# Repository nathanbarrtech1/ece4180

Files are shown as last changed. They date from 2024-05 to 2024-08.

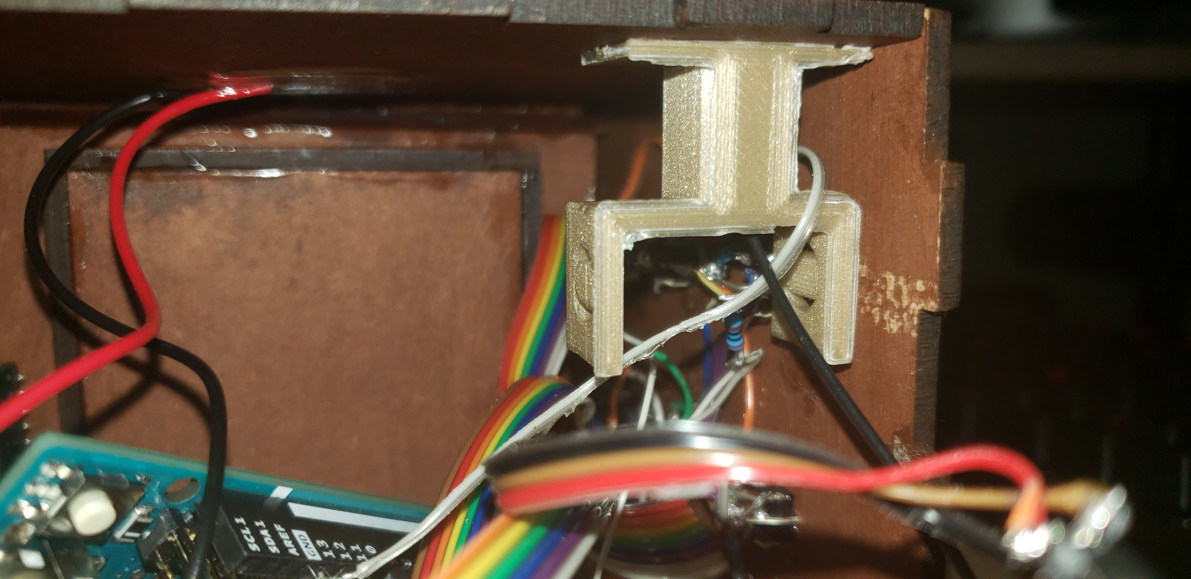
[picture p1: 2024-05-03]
3D Print/image.jpg

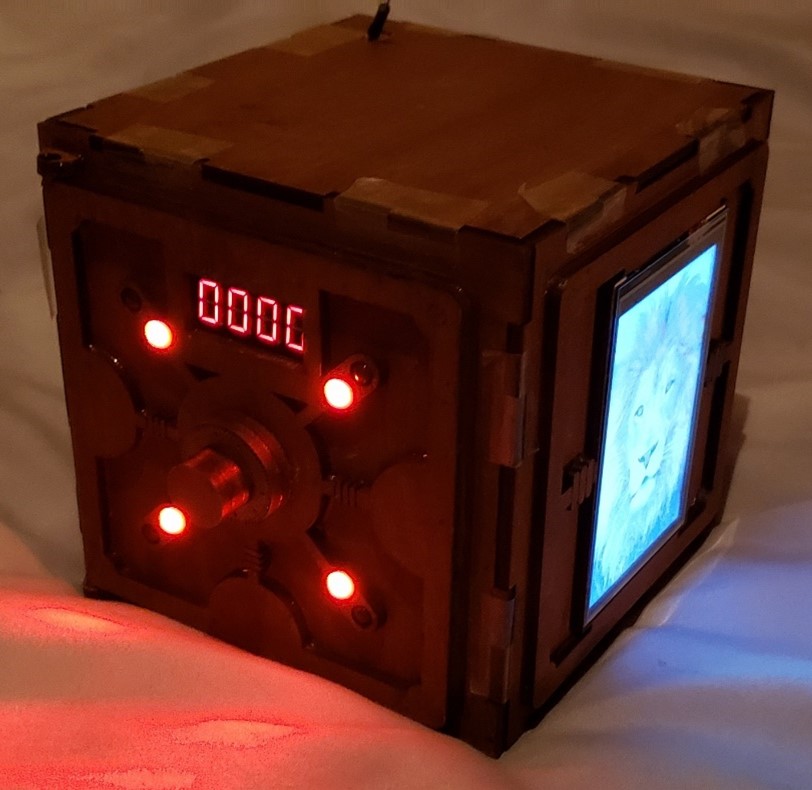
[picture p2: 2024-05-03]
pictures/frontviewon.jpg

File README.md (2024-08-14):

# Puzzle Box

This project goal was to develop a puzzle box consisting of multiple puzzles:

1. LCD Sliding Block Puzzle
2. Accelerometer Puzzle
3. Lights Up Game Puzzle
4. Knocking Puzzle
5. Code Guessing Puzzle

### Notes during recreation

Must include the SPFD5408 libary to arduino along with others in the library manager to compile all code.

Also, adjust the outer dimensions of the box in the laser cut by approximately 10% to adjust for inadequate space during my project.

Some of the laser cut designs are not correct, many last minute changes were made and lost after cutting.

### Below is the demo video for the puzzle box
Puzzle Box (https://www.youtube.com/watch?v=jFf0oDgVzTA)

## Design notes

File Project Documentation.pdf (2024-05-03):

## Arduino Based Puzzle Box

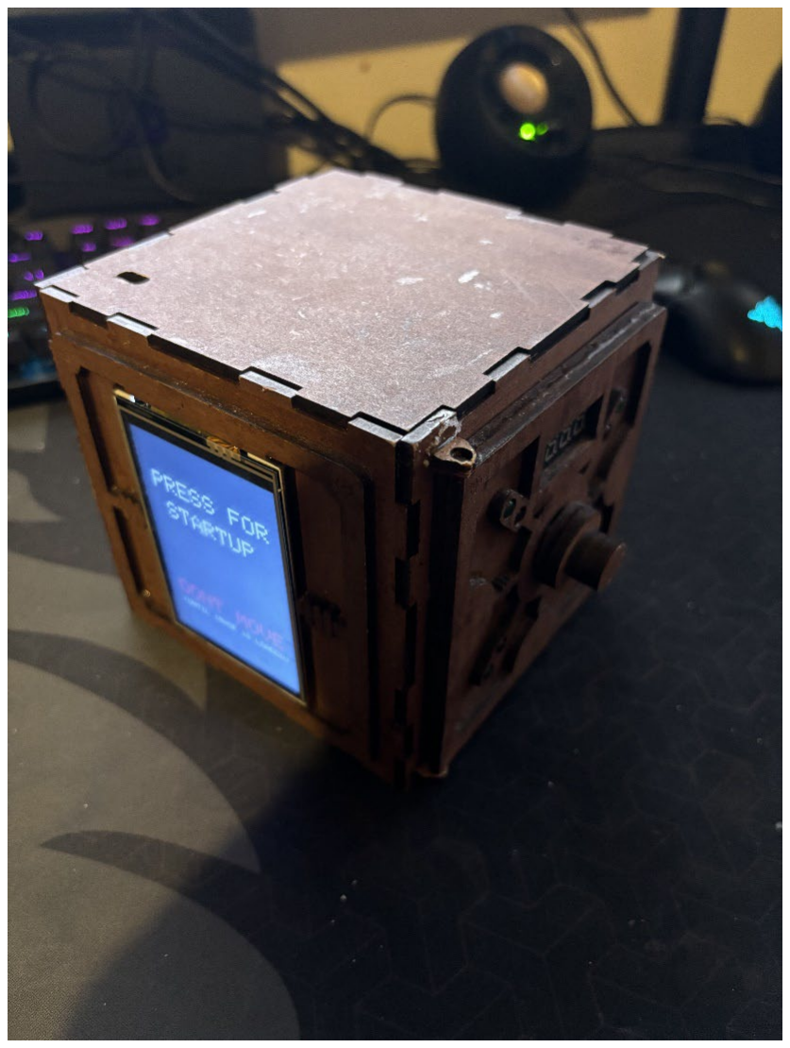
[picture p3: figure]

Description of Prototype
The project is a buzzle box that has three interlocking interconnected puzzles that must be solved to open the puzzle box and retrieve the prize inside.
The first puzzle is a knocking program that requires the user to input a specific sequence of knocks to solve the puzzle. An LED will light up for every correct knock. If a knock is incorrect, 4 green LEDs will flash for too fast and 4 red LEDs will flash for too slow. There is a total of 8 knocks in the sequence.

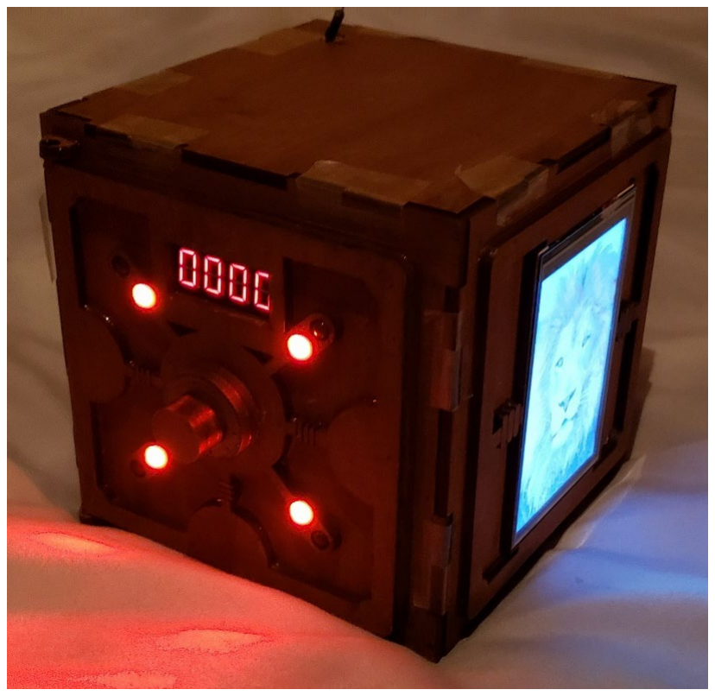
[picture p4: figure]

The second puzzle is a touchscreen LCD that contains a 3x3 sliding block puzzle. The image shows the solved puzzle on the right side of the box. When not solved, there will be 8 image tiles with an empty space for the ninth. The image tiles can be moved to the empty space thus emptying their previous spots. The goal is to organize the image so that all tiles are in the right spot. Once that is done, the image will complete itself and only one puzzle will be left. The third puzzle is a four-digit guessing game where red LEDs will light up for every correct number in the wrong position. For example, if the code is 0123, inputting 1000 will light

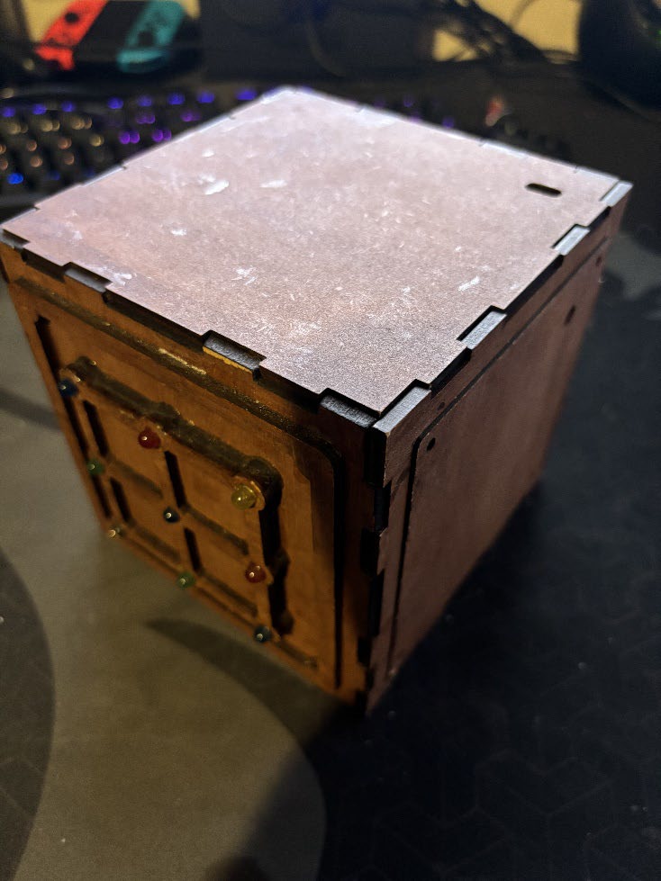
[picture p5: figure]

up 2 red LEDs and 1032 will light up 4 red LEDs. Green LEDs will light up for every correct number in the correct position. For example, if the code is 0123, inputting 0100 will light up 2 green LEDs and 0124 will light up 3 green LEDs.
There is a fourth puzzle that features a 3x3 grid of LEDs and buttons on the LED screen where pushing one of the LED button combos will turn on all adjacent lights that are off and turn off all adjacent light that are on (including itself).
There is a fifth puzzle where the puzzle box is rotated a certain amount then a pushbutton is pressed. The lights on the front will light up green when the player has not moved far enough, red when the player moved too far, and red and green when the player succeeded. This continues for four iterations where the player has five attempts per iteration before the puzzle restarts. Video Demo (https://www.youtube.com/watch?v=jFf0oDgVzTA)

Difficulties faced
There were a lot of problems that cropped up as the project continued. The biggest issue is that, by using the same size of the box as the original design while simultaneously adding a multitude of parts, my puzzle box ran out of room quite quickly. Another problem was the soldering. I soldered over 70 connections which was extremely difficult considering the fact that these connections would be placed side by side. The soldering was redone with crimping for a much cleaner and less error-prone circuit.
Furthermore, for reasons still unknown, I was unable to properly solder the middle LED of the 3x3 grid. The connection would always depend on how I positions the soldered parts and I would have to hold it in place with my finger for the connection to work, something impossible to maintain since I cant always hold that connection. It was also extremely difficult and time-consuming to glue in the push buttons such that they would not lock down the LEDs preventing them from pushing the button. I had to remove button, scrape off the glue, and reglue multiple times. I also had to flatten the LED wires at the LED’s base then glue the whole base creating a flat surface to interact with the push button. Because of this, the pushbuttons were removed and the LEDS were instead adjusted using the touchscreen.
Another weird issue was that the rotary encoder seemed to create some sort of open circuit on the Arduino that could only be solved by connecting a wire to pin 2 (a pin that is not being used). Only pin 2 worked and other unused pins did not. Furthermore, the pin had to be closed manually by pinching the other end of the wire with two fingers to close the circuit. Connecting the wire to 5V or GND did not solve the issue and using fingers was the only solution I found. This issue was solved by properly resoldering all components, crimping, and heat shrinking.

Some other difficulties include needing to laser cut the same part multiple times because of issues with the dimensions and wasting time due to shipping time. In the end, a box was completed, but it is too small to properly fit the components which has caused some issues from poor wiring to unstable connections.

Parts list:
- TFT touchscreen LCD
- Arduino MEGA
- Many wires, solder, crimp
- Rotary Encoder
- 17 LEDs and 220 Ω resistors
- 9 Buttons and 1MΩ resistors
- Seven segment display
- 1/8. in MDF
- 2 9V batteries
- Glue
- Servo motor
- Accelerometer
- SD reader

Algorithms used
The only algorithms used were those that checked if a knock was correct, whether to 4-digit code was correct, whether a chosen tile can be moved to a chosen location, and other minor algorithms that helped the aforementioned algorithms become simpler. I did not use any of the well-known algorithms like bubble sort and all of my algorithms were self-made.

Pin List

Object | Name | Pin
Servo Motor | Servo Pin | 23
Rotary Encoder | ButtonPin | 17
Rotary Encoder | PinA | 19
Rotary Encoder | PinB | 18
LCD | LCD Pin | 9
TFT | LCD_RD | A0
TFT | LCD_WR | A1
TFT | LCD_CD | A2
TFT | LCD_CS | A3
TFT | LCD_RESET | A4
Touchscreen | YP | A2
Touchscreen | XM | A3
Touchscreen | YM | 8
Touchscreen | XP | 9
Touchscreen | SD_CS | 53
Piezo | Sensor | A8
LED | correctNumLEDs | 27
LED | correctNumLEDs | 29
LED | correctNumLEDs | 37
LED | correctNumLEDs | 35
LED | correctPlaceLEDs | 25

LED | correctPlaceLEDs | 31
LED | correctPlaceLEDs | 39
LED | correctPlaceLEDs | 33
LED | {1,1} | 14
LED | {1,2} | 41
LED | {1,3} | 10
LED | {2,1} | 15
LED | {2,2} | 43
LED | {2,3} | 11
LED | {3,1} | 16
LED | {3,2} | 45
LED | {3,3} | 12
SevSeg | digitPins | 22
SevSeg | digitPins | 34
SevSeg | digitPins | 38
SevSeg | digitPins | 44
SevSeg | segmentPins | 26
SevSeg | segmentPins | 42
SevSeg | segmentPins | 36
SevSeg | segmentPins | 28
SevSeg | segmentPins | 24
SevSeg | segmentPins | 30
SevSeg | segmentPins | 40

SevSeg | segmentPins | 32

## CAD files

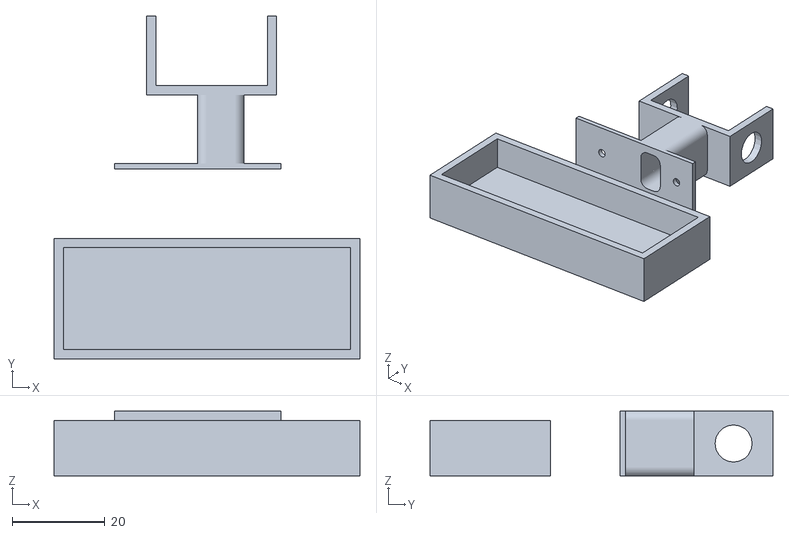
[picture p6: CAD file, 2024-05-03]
3D Print/parts.stl
66.0 x 74.0 x 14.0

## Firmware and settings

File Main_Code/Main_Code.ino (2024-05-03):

/////////////////////////////////
/////////// INCLUDES ////////////
/////////////////////////////////

#include <Servo.h>
#include <Encoder.h>
#include "SevSeg.h"
#include <TimerOne.h>
#include <SPFD5408_Adafruit_GFX.h>
#include <SPFD5408_Adafruit_TFTLCD.h>
#include <SPI.h>
#include <SD.h>
#include <SPFD5408_TouchScreen.h>

/////////////////////////////////
/////// SHARED CONSTANTS ////////
/////////////////////////////////

#define NUM_PUZZLES     5

#define VAULT           0
#define LCD             1
#define KNOCK           2
#define LEDS            3
#define ACC             4

#define DEBUG           1
#define SERVOPIN        23

/////////////////////////////////
//////// VAULT CONSTANTS ////////
/////////////////////////////////

#define ButtonPin       17
#define PinA            19
#define PinB            18
#define DEBOUNCE_DELAY  150

/////////////////////////////////
//////// KNOCK CONSTANTS ////////
/////////////////////////////////

#define NUM_OF_KNOCKS 8

/////////////////////////////////
//////// KNOCK CONSTANTS ////////
/////////////////////////////////

#define LCD_PIN 9

/////////////////////////////////
///////// LED CONSTANTS /////////
/////////////////////////////////

#define BLACK   0x0000
#define BLUE    0x001F
#define RED     0xF800
#define GREEN   0x07E0
#define CYAN    0x07FF
#define MAGENTA 0xF81F
#define YELLOW  0xFFE0
#define WHITE   0xFFFF

#define LCD_RD A0
#define LCD_WR A1
#define LCD_CD A2
#define LCD_CS A3
#define LCD_RESET A4

#define YP A2
#define XM A3
#define YM 8
#define XP 9
#define SD_CS 53

#define COMPLETE A5
#define WIDTH 106
#define HEIGHT 160

#define LED_DEBOUNCE 350

/////////////////////////////////
/////// SHARED VARIABLES ////////
/////////////////////////////////

int valid_puzzles[NUM_PUZZLES] = {false, false, true, false, false};
int solved_puzzles[NUM_PUZZLES] = {false, false, false, false, false};
Adafruit_TFTLCD tft(LCD_CS, LCD_CD, LCD_WR, LCD_RD, A4);
TouchScreen ts = TouchScreen(XP, YP, XM, YM, 300);

/////////////////////////////////
//////// VAULT VARIABLES ////////
/////////////////////////////////

Encoder myEnc(PinA,  PinB);
SevSeg sevseg;
Servo lockServo;

int currButtonVal;
int lastButtonVal;
int rightPos;
int rightNum;


int corrCode[4];
int guessCode[4] = {0, 0, 0, 0};
byte correctNumLEDs[4] =  {27, 29, 37, 35};  //Pin numbers for correct number LEDs (Indicate a correct digit)
byte correctPlaceLEDs[4] = {25, 31, 39, 33}; //Pin numbers for correct place LEDs (Indicate a correct digit in the correct place)

unsigned long buttonTime = 0;
int currNum = 0;
int numGuesses = 0;
int numPresses = 0;
int tempPos = -999;
long oldPosition  = -999;
long newPosition = -999;

/////////////////////////////////
//////// KNOCK VARIABLES ////////
/////////////////////////////////

const int sensorPin = A8;
const int threshold = 300;
byte LED[NUM_OF_KNOCKS] = {25, 31, 39, 33, 27, 29, 37, 35};
int minKnockTimes[NUM_OF_KNOCKS] = {0,      0   , 1000, 2000, 0   , 1000, 3000, 0   };
int maxKnockTimes[NUM_OF_KNOCKS] = {100000, 1000, 3000, 4000, 1000, 3000, 6000, 4000};
const int ledPin[3][3]    = {{5,  6,  7} , {8,  9,  10}, {11, 12, 13}};
int currentKnock = 0;
long int timer;
bool knockValid = false;

/////////////////////////////////
///////// LED VARIABLES /////////
/////////////////////////////////

int ledColors[3][3] =
{
  {BLUE,  RED,    YELLOW},
  {GREEN, BLUE,   RED},
  {WHITE, GREEN,  BLUE}
};

const int LED_PUZZLE[3][3] =
{
  {14, 41, 10},
  {15, 43, 11},
  {16, 45, 12}
};

bool ledOn[3][3] =
{
  {LOW, LOW, LOW},
  {LOW, LOW, LOW},
  {LOW, LOW, LOW}
};

long ledTimer = 0;

void setup()
{
  /////////////////////////////////
  ////////// SHARED SETUP /////////
  /////////////////////////////////
  
  Serial.begin (9600);
  Serial.println("BEGIN!");

  /////////////////////////////////
  ////////// VAULT SETUP //////////
  /////////////////////////////////
  
  pinMode(ButtonPin, INPUT_PULLUP);

  attachInterrupt(digitalPinToInterrupt(PinA), updateEncoder, CHANGE);
  
  lockServo.attach(SERVOPIN);
  lockServo.write(90);
  randomSeed(analogRead(A7));
  generateNewCode();

  for (int i = 0 ; i <= 3 ; i++)
  {
    pinMode(correctNumLEDs[i], OUTPUT);
    pinMode(correctPlaceLEDs[i], OUTPUT);
  }

  byte numDigits = 4;
  byte digitPins[] = {22, 34, 38, 44};
  byte segmentPins[] = {26, 42, 36, 28, 24, 30, 40, 32};

  bool resistorsOnSegments = true;
  byte hardwareConfig = COMMON_CATHODE;
  sevseg.begin(hardwareConfig, numDigits, digitPins, segmentPins, resistorsOnSegments);
  sevseg.setBrightness(90);

  /////////////////////////////////
  ////////// KNOCK SETUP //////////
  /////////////////////////////////

  pinMode(sensorPin, INPUT);

  pinMode(LCD_PIN, INPUT_PULLUP);

  if (!DEBUG)
    generateKnock();

  /////////////////////////////////
  /////////// TFT SETUP ///////////
  /////////////////////////////////


  /////////////////////////////////
  /////////// LED SETUP ///////////
  /////////////////////////////////

  start();
  LED_PUZZLE_SETUP();

}

void loop()
{
  sevseg.refreshDisplay();
  if (solved_puzzles[LCD] && solved_puzzles[KNOCK] && !solved_puzzles[VAULT])
  {
    valid_puzzles[VAULT] = true;
  }

  if (valid_puzzles[LCD])
  {
    
  }

  ////////////////////////////////
  ///////////// SERVO ////////////
  ////////////////////////////////

  if (checkSolved())
    lockServo.write(130);

  ////////////////////////////////
  ////////// VAULT LOOP //////////
  ////////////////////////////////

  if (valid_puzzles[VAULT])
  {
    if (numPresses == 4) checkNumber();
    else updateNumber();
  }
  else Serial.println("HI");

  ////////////////////////////////
  ////////// KNOCK LOOP //////////
  ////////////////////////////////

  if (valid_puzzles[KNOCK])
  {
    if (currentKnock == 8)
    {
      resetKnocks();
      Celebration();
      valid_puzzles[KNOCK] = false;
      solved_puzzles[KNOCK] = true;
    }
    readAndCheckKnock();
  }

  ////////////////////////////////
  /////////// LED LOOP ///////////
  ////////////////////////////////

  if (valid_puzzles[LEDS] && millis() - ledTimer > LED_DEBOUNCE)
  {
    LED_PUZZLE_ALG();
    IS_LED_PUZZLE_SOLVED();
  }
}
/////////////////////////////////
//////// SHARED FUNCTIONS ///////
/////////////////////////////////

int getCoordinate(TSPoint p, char axis)
{
  if (axis == 'y')
  {
    int x = map(p.y, 112, 800, 0, tft.width()  - 1);

    if       (x >= 2 * tft.width() / 3)   return 0;
    else if  (x >=     tft.width() / 3)   return 1;
    else                                  return 2;
  }

  if (axis == 'x')
  {
    int y = map(p.x,  96, 947, 0, tft.height() - 1);

    if       (y >= 2 * tft.height() / 3)  return 0;
    else if  (y >=     tft.height() / 3)  return 1;
    else                                  return 2;
  }
}

#define BUFFPIXEL 20           //Drawing speed, 20 is meant to be the best but you can use 60 altough it takes a lot of uno's RAM         

//Drawing function, reads the file from the SD card and do the
//conversion and drawing, also it shows messages on the Serial monitor in case of a problem
//No touchy to this function :D

void bmpDraw(char *filename, int x, int y) {

  File     bmpFile;
  int      bmpWidth, bmpHeight;   // W+H in pixels
  uint8_t  bmpDepth;              // Bit depth (currently must be 24)
  uint32_t bmpImageoffset;        // Start of image data in file
  uint32_t rowSize;               // Not always = bmpWidth; may have padding
  uint8_t  sdbuffer[3 * BUFFPIXEL]; // pixel in buffer (R+G+B per pixel)
  uint16_t lcdbuffer[BUFFPIXEL];  // pixel out buffer (16-bit per pixel)
  uint8_t  buffidx = sizeof(sdbuffer); // Current position in sdbuffer
  boolean  goodBmp = false;       // Set to true on valid header parse
  boolean  flip    = true;        // BMP is stored bottom-to-top
  int      w, h, row, col;
  uint8_t  r, g, b;
  uint32_t pos = 0, startTime = millis();
  uint8_t  lcdidx = 0;
  boolean  first = true;

  if ((x >= tft.width()) || (y >= tft.height())) return;

  Serial.println();
  progmemPrint(PSTR("Loading image '"));
  Serial.print(filename);
  Serial.println('\'');
  // Open requested file on SD card
  if ((bmpFile = SD.open(filename)) == NULL) {
    progmemPrintln(PSTR("File not found"));
    return;
  }

  // Parse BMP header
  if (read16(bmpFile) == 0x4D42) { // BMP signature
    progmemPrint(PSTR("File size: ")); Serial.println(read32(bmpFile));
    (void)read32(bmpFile); // Read & ignore creator bytes
    bmpImageoffset = read32(bmpFile); // Start of image data
    progmemPrint(PSTR("Image Offset: ")); Serial.println(bmpImageoffset, DEC);
    // Read DIB header
    progmemPrint(PSTR("Header size: ")); Serial.println(read32(bmpFile));
    bmpWidth  = read32(bmpFile);
    bmpHeight = read32(bmpFile);
    if (read16(bmpFile) == 1) { // # planes -- must be '1'
      bmpDepth = read16(bmpFile); // bits per pixel
      progmemPrint(PSTR("Bit Depth: ")); Serial.println(bmpDepth);
      if ((bmpDepth == 24) && (read32(bmpFile) == 0)) { // 0 = uncompressed

        goodBmp = true; // Supported BMP format -- proceed!
        progmemPrint(PSTR("Image size: "));
        Serial.print(bmpWidth);
        Serial.print('x');
        Serial.println(bmpHeight);

        // BMP rows are padded (if needed) to 4-byte boundary
        rowSize = (bmpWidth * 3 + 3) & ~3;

        // If bmpHeight is negative, image is in top-down order.
        // This is not canon but has been observed in the wild.
        if (bmpHeight < 0) {
          bmpHeight = -bmpHeight;
          flip      = false;
        }

        // Crop area to be loaded
        w = bmpWidth;
        h = bmpHeight;
        if ((x + w - 1) >= tft.width())  w = tft.width()  - x;
        if ((y + h - 1) >= tft.height()) h = tft.height() - y;

        // Set TFT address window to clipped image bounds
        tft.setAddrWindow(x, y, x + w - 1, y + h - 1);

        for (row = 0; row < h; row++) { // For each scanline...
          // Seek to start of scan line.  It might seem labor-
          // intensive to be doing this on every line, but this
          // method covers a lot of gritty details like cropping
          // and scanline padding.  Also, the seek only takes
          // place if the file position actually needs to change
          // (avoids a lot of cluster math in SD library).
          if (flip) // Bitmap is stored bottom-to-top order (normal BMP)
            pos = bmpImageoffset + (bmpHeight - 1 - row) * rowSize;
          else     // Bitmap is stored top-to-bottom
            pos = bmpImageoffset + row * rowSize;
          if (bmpFile.position() != pos) { // Need seek?
            bmpFile.seek(pos);
            buffidx = sizeof(sdbuffer); // Force buffer reload
          }

          for (col = 0; col < w; col++) { // For each column...
            // Time to read more pixel data?
            if (buffidx >= sizeof(sdbuffer)) { // Indeed
              // Push LCD buffer to the display first
              if (lcdidx > 0) {
                tft.pushColors(lcdbuffer, lcdidx, first);
                lcdidx = 0;
                first  = false;
              }
              bmpFile.read(sdbuffer, sizeof(sdbuffer));
              buffidx = 0; // Set index to beginning
            }

            // Convert pixel from BMP to TFT format
            b = sdbuffer[buffidx++];
            g = sdbuffer[buffidx++];
            r = sdbuffer[buffidx++];
            lcdbuffer[lcdidx++] = tft.color565(r, g, b);
          } // end pixel
        } // end scanline
        // Write any remaining data to LCD
        if (lcdidx > 0) {
          tft.pushColors(lcdbuffer, lcdidx, first);
        }
        progmemPrint(PSTR("Loaded in "));
        Serial.print(millis() - startTime);
        Serial.println(" ms");
      } // end goodBmp
    }
  }

  bmpFile.close();
  if (!goodBmp) progmemPrintln(PSTR("BMP format not recognized."));
}

// These read 16- and 32-bit types from the SD card file.
// BMP data is stored little-endian, Arduino is little-endian too.
// May need to reverse subscript order if porting elsewhere.

uint16_t read16(File f) {
  uint16_t result;
  ((uint8_t *)&result)[0] = f.read(); // LSB
  ((uint8_t *)&result)[1] = f.read(); // MSB
  return result;
}

uint32_t read32(File f) {
  uint32_t result;
  ((uint8_t *)&result)[0] = f.read(); // LSB
  ((uint8_t *)&result)[1] = f.read();
  ((uint8_t *)&result)[2] = f.read();
  ((uint8_t *)&result)[3] = f.read(); // MSB
  return result;
}

// Copy string from flash to serial port
// Source string MUST be inside a PSTR() declaration!
void progmemPrint(const char *str) {
  char c;
  while (c = pgm_read_byte(str++)) Serial.print(c);
}

// Same as above, with trailing newline
void progmemPrintln(const char *str) {
  progmemPrint(str);
  Serial.println();
}

/////////////////////////////////
//////// VAULT FUNCTIONS ////////
/////////////////////////////////

void updateEncoder() {
  newPosition = myEnc.read();
}

void generateNewCode()                                        //Function to generate a new random code
{
  Serial.print("Code: ");

  if (DEBUG)
  {
    for (int i = 0 ; i <= 3 ; i++)                              //Loops through the four digits and assigns a random number to each
    {
      corrCode[i] = i;                                   //Generate a random number for each digit
      Serial.print(corrCode[i]);                                    //Display the code on Serial monitor for debugging
    }
  }
  else
  {
    for (int i = 0 ; i <= 3 ; i++)                              //Loops through the four digits and assigns a random number to each
    {
      corrCode[i] = random(0, 9);                                   //Generate a random number for each digit
      Serial.print(corrCode[i]);                                    //Display the code on Serial monitor for debugging
    }
  }
}

void displayNumber()
{
  int num = 0;

  for (int i = 0; i < 4; i++)
  {
    num *= 10;
    if (numPresses == i)
    {
      num += currNum;
    }
    else if (guessCode != 0 && guessCode != 10)
      num += guessCode[i];
  }
  
  sevseg.setNumber(num, 4);
  sevseg.refreshDisplay();
}


void checkNumber()
{
  for (int i = 0; i < 4; i++) Serial.print(guessCode[i]);
  Serial.println();
  rightPos = 0;
  rightNum = 0;
  numGuesses++;
  numPresses = 0;
  bool usedNums[4] = {false, false, false, false};

  for (int i = 0; i < 4; i++)
  {
    if (guessCode[i] == corrCode[i])
    {
      rightPos++;
      usedNums[i] = true;
    }
  }

  checkVaultSolved();

  for (int i = 0; i < 4; i++)
    for (int j = 0; j < 4; j++)
    {
      if (guessCode[i] == corrCode[j] && guessCode[i] != corrCode[i] && !usedNums[j])
      {
        rightNum++;
        usedNums[j] = true;
        break;
      }
    }

  updateLEDs(rightNum, rightPos);
  for (int i = 0; i < 4; i++) guessCode[i] = 0;
}

void updateLEDs (int corNum, int corPla)                        //Function to update the LEDs to reflect the guess
{
  for (int i = 0 ; i < 4 ; i++)                                //First turn all LEDs off
  {
    digitalWrite(correctNumLEDs[i], LOW);
    digitalWrite(correctPlaceLEDs[i], LOW);
  }
  for (int j = 0 ; j <= corNum - 1 ; j++)                       //Turn on the number of correct digits in wrong place LEDs
  {
    digitalWrite(correctNumLEDs[j], HIGH);
  }
  for (int k = 0 ; k <= corPla - 1 ; k++)                       //Turn on the number of correct digits in the correct place LEDs
  {
    digitalWrite(correctPlaceLEDs[k], HIGH);
  }
}

void updateNumber()
{
  while (!buttonPressed())
  {
    byte incSize = 3;
    if (newPosition != oldPosition) {
      if (newPosition - oldPosition < -1 * incSize)           currNum--;
      else if (newPosition - oldPosition > incSize) currNum++;
      else return;
      oldPosition = newPosition;

      if (currNum > 9) currNum = 0;
      if (currNum < 0) currNum = 9;
    }
    displayNumber();
  }
  enterNumber();
}

bool buttonPressed() {
  currButtonVal = digitalRead(ButtonPin);
  if (!currButtonVal && currButtonVal != lastButtonVal && (buttonTime - millis()) > DEBOUNCE_DELAY)
  {
    buttonTime = millis();
    return true;
  }
  lastButtonVal = currButtonVal;
  return false;
}

void enterNumber()
{
  guessCode[numPresses] = currNum;
  currNum = 0;
  numPresses++;
  lastButtonVal = currButtonVal;
}

void checkVaultSolved()
{
  if (rightPos == 4)
  {
    sevseg.blank();
    sevseg.refreshDisplay();
    sevseg.setNumber(numGuesses, 0);
    
    valid_puzzles[VAULT] = false;
    solved_puzzles[VAULT] = true;
    Celebration();
  }
  else sevseg.setNumber(0, 4);
}

bool checkSolved()
{
  for (int i = 0; i < NUM_PUZZLES; i++)
    if (!solved_puzzles[i])
      return false;

  return true;
}

/////////////////////////////////
//////// KNOCK FUNCTIONS ////////
/////////////////////////////////

void generateKnock()
{
  bool b = false;
  for (int i = 1; i < NUM_OF_KNOCKS; i++)
  {
    int temp;

    if (!b)
      temp = random(4);
    else
      temp = random(3);

    if (temp == 3)
      b = true;

    minKnockTimes[i] = temp * 1000;
    maxKnockTimes[i] = (temp + 2) * 1000;

    Serial.print(temp);
    Serial.print(", ");
    Serial.println(minKnockTimes[i]);
  }
}

void readAndCheckKnock()
{
  int val = analogRead(sensorPin);

  if (val >= threshold)
  {
    if (millis() - timer >= minKnockTimes[currentKnock] && millis() - timer <= maxKnockTimes[currentKnock])
    {
      Serial.print("SUCCESS ");
      Serial.println(currentKnock);
      digitalWrite(LED[currentKnock], HIGH);
      currentKnock++;
      delay(300);
    }

    else if (millis() - timer < minKnockTimes[currentKnock])
    {
      resetKnocks();
      delay(100);
      for (int i = 0; i < 4; i++)
        digitalWrite(correctPlaceLEDs[i], HIGH);
      delay(1000);
      resetKnocks();
    }

    timer = millis();
  }

  if (millis() - timer > maxKnockTimes[currentKnock])
  {
    resetKnocks();
    delay(100);
    for (int i = 0; i < 4; i++)
      digitalWrite(correctNumLEDs[i], HIGH);
    delay(1000);
    resetKnocks();
  }
}

void resetKnocks()
{
  currentKnock = 0;
  for (int i = 0; i < NUM_OF_KNOCKS; i++)
  {
    digitalWrite(LED[i], LOW);
  }
}

void Celebration()
{
  int delayTime = 150;

  for (int i = 0; i < 4; i++)
  {
    if (i % 2 == 0)
    {
      digitalWrite(correctNumLEDs[i], HIGH);
      delay(delayTime);
      digitalWrite(correctNumLEDs[i], LOW);
      delay(delayTime);
      digitalWrite(correctPlaceLEDs[i], HIGH);
      delay(delayTime);
      digitalWrite(correctPlaceLEDs[i], LOW);
      delay(delayTime);
    }

    else
    {
      digitalWrite(correctPlaceLEDs[i], HIGH);
      delay(delayTime);
      digitalWrite(correctPlaceLEDs[i], LOW);
      delay(delayTime);
      digitalWrite(correctNumLEDs[i], HIGH);
      delay(delayTime);
      digitalWrite(correctNumLEDs[i], LOW);
      delay(delayTime);
    }
  }

  for (int i = 0; i < 4; i++)
  {
    digitalWrite(correctPlaceLEDs[i], HIGH);
    delay(delayTime);
    digitalWrite(correctPlaceLEDs[i], LOW);
    delay(delayTime);
  }

  for (int i = 3; i >= 0; i--)
  {
    digitalWrite(correctNumLEDs[i], HIGH);
    delay(delayTime);
    digitalWrite(correctNumLEDs[i], LOW);
    delay(delayTime);
  }
}
/////////////////////////////////
///////// LED FUNCTIONS /////////
/////////////////////////////////

void LED_PUZZLE_ALG()
{

  TSPoint p;
  do
  {
    p = ts.getPoint();
    pinMode(XM, OUTPUT);  //.kbv ALWAYS restore pinMode()
    pinMode(YP, OUTPUT);
  }
  while (p.z < ts.pressureThreshhold);



  int ledRow = getCoordinate(p, 'x');
  int ledCol = 2 - getCoordinate(p, 'y');

  for (int k = -1; k <= 1; k++)
    for (int l = -1; l <= 1; l++)
      if (ledRow + k >= 0 && ledRow + k < 3 && ledCol + l >= 0 && ledCol + l < 3 && (k == 0 || l == 0))
      {
        ledOn[ledRow + k][ledCol + l] = !ledOn[ledRow + k][ledCol + l];
        if (k == 0 && l == 0)
          Serial.println(ledOn[ledRow + k][ledCol + l]);

        digitalWrite(LED_PUZZLE[ledRow + k][ledCol + l],  ledOn[ledRow + k][ledCol + l]);
      }

  ledTimer = millis();

}
void IS_LED_PUZZLE_SOLVED()
{
  for (int i = 0; i < 3; i++)
    for (int j = 0; j < 3; j++)
    {
      if (!ledOn[i][j]) return;
    }

  for (int i = 0; i < 3; i++)
    for (int j = 0; j < 3; j++)
    {
      ledOn[i][j] = false;
      digitalWrite(LED_PUZZLE[i][j], LOW);
    }
    
  valid_puzzles[LEDS] = false;
  solved_puzzles[LEDS] = true;
  
  ledCelebration();
  ledCelebration();
  ledCelebration();
}

void start()
{
  pinMode(COMPLETE, OUTPUT);
  Serial.begin(9600);
  tft.reset();
  uint16_t identifier = tft.readID();
  pinMode(10, OUTPUT);
  tft.begin(identifier);
  if (!SD.begin(SD_CS)) {
    progmemPrintln(PSTR("failed!"));
    return;
  }
  tft.fillScreen(BLACK);
}

void LED_PUZZLE_SETUP()
{
  tft.setRotation(1);
  randomSeed(micros());
  long rand1[2];
  long rand2[2];

  bool rand1CC = false;
  bool rand2CC = false;

  while (!(rand1CC && rand2CC))
  {
    long temprand1[2] = {random(3), random(3)};
    long temprand2[2] = {random(3), random(3)};

    *rand1 = *temprand1;
    *rand2 = *temprand2;

    rand1CC = (rand1[0] + rand1[1]) % 2 == 0 && rand1[0] != 1 && rand1[1] != 1;
    rand2CC = (rand2[0] + rand2[1]) % 2 == 0 && rand2[0] != 1 && rand2[1] != 1;
  }
  delay(1000);

  digitalWrite(LED_PUZZLE[rand1[0]][rand1[1]], HIGH);
  digitalWrite(LED_PUZZLE[rand2[0]][rand2[1]], HIGH);

  ledOn[rand1[0]][rand1[1]] = HIGH;
  ledOn[rand2[0]][rand2[1]] = HIGH;
}
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

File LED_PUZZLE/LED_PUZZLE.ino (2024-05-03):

const int buttonPin[3][3] = {{A0, A1, A2}, {A3, A4, A5}, {2,  3,  4 }};
const int ledPin[3][3]    = {{5,  6,  7} , {8,  9,  10}, {11, 12, 13}};
bool ledOn[3][3] = {{LOW, LOW, LOW}, {LOW, LOW, LOW}, {LOW, LOW, LOW}};

// variables will change:
int buttonState = 0;         // variable for reading the pushbutton status

void setup() {
  Serial.begin(9600);
  // initialize the LED pin as an output:
  for (int i = 0; i < 3; i++)
  {
    for (int j = 0; j < 3; j++)
    {
      pinMode(buttonPin[i][j], INPUT);
      pinMode(ledPin[i][j], OUTPUT);
      
    }
  }
  
  while (true)
  {
    if (digitalRead(A4) != HIGH)
    {
      delay(10);
      continue;
    }
    randomSeed(micros());
    long rand1[2] = {random(3), random(3)};
    long rand2[2] = {random(3), random(3)};

    bool rand1CC = (rand1[0] + rand1[1]) % 2 == 0 && rand1[0] != 1 && rand1[1] != 1;
    bool rand2CC = (rand2[0] + rand2[1]) % 2 == 0 && rand2[0] != 1 && rand2[1] != 1;
    
    delay(1000);
    
    digitalWrite(ledPin[rand1[0]][rand1[1]], HIGH);
    digitalWrite(ledPin[rand2[0]][rand2[1]], HIGH);
  
    ledOn[rand1[0]][rand1[1]] = HIGH;
    ledOn[rand2[0]][rand2[1]] = HIGH;
    
    break;
  }
}

void loop() 
{
  

  for (int i = 0; i < 3; i++)
  {
    for (int j = 0; j < 3; j++)
    {
      buttonState = digitalRead(buttonPin[i][j]);
      
      if (buttonState == HIGH)
      {
        for (int k = -1; k <= 1; k++)
          for (int l = -1; l <= 1; l++)
            if (i + k >= 0 && i + k < 3 && j + l >= 0 && j + l < 3 && (k == 0 || l == 0))
            {
              ledOn[i + k][j + l] = !ledOn[i + k][j + l];
              Serial.println(ledOn[i + k][j + l]);
              digitalWrite(ledPin[i + k][j + l],  ledOn[i + k][j + l]);
            }
        delay(500);
      }
    }
  }   
}
